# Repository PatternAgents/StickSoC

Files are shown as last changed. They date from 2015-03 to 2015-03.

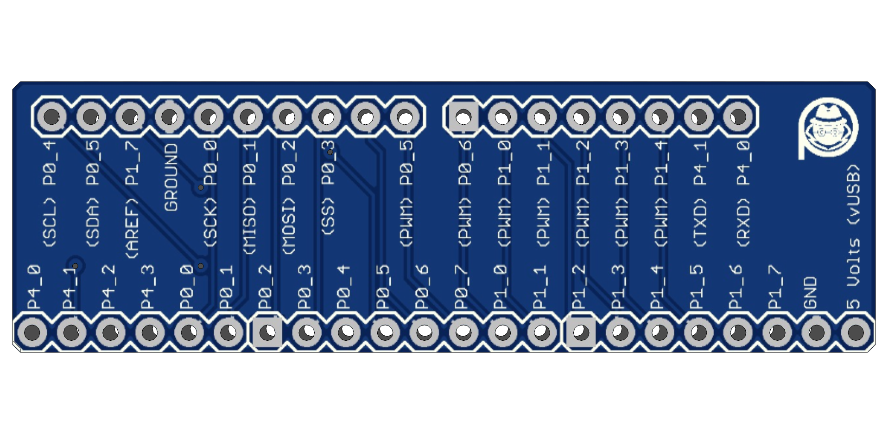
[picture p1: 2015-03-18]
StickSoc/StickSoc_Right/images/StickSoC_Right_top.png

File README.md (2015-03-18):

StickSoC
=============

PatternAgents StickSoC - add on boards for the Cypress CY8CKIT-049 (PSoC4)

[PatternAgents StickSoC  
*PatternAgents StickSoC*](http://www.patternagents.com/projects/StickSoC.html)

The PatternAgents StickSoC allows the Cypress CY8CKIT-049 board to accept Arduino type Shields.

Features:

        DC Barrel Jack for Providing VIN, 12Vdc-16Vdc to Shields that need it.

        PTC Resetable Fuse for VIN
	
        USB/5.0Vdc to 3.3Volt Voltage Regulator
	
	Arduino Uno/Leonardo Compatible Shield

You can read more about the PSoC4 Integrated Circuit used here : http://www.cypress.com/?mpn=CY8C4245AXI-483

[  
*Licensing CC BY-NC-SA 4.0*](http://creativecommons.org/licenses/by-nc-sa/4.0/)

PatternAgents uses the increasingly popular business model called "Dual Licensing" 
in which both the open source software distribution mechanism and traditional commercial software distribution models are combined.

Open Source Projects:        

If you are developing and distributing open source applications under the Creative Commons CC BY-NC-SA 4.0, 
as published by the Creative Commons Foundation, then you are free to use the PatternAgents hardware/software under the CC BY-NC-SA 4.0 license. 
Please note that CC BY-NC-SA 4.0 requires that all modifications to the original code as well as all Derivative Works 
must also be released under the terms of the CC BY-NC-SA 4.0 license.

Closed Source Projects:

If you are developing and distributing traditional closed source or commercial applications, 
you must purchase a PatternAgents commercial use license, 
which is specifically designed for users interested in retaining the proprietary status of their designs and code. 
All PatternAgents commercial licenses expressly supersede the CC BY-NC-SA 4.0 license. 
This means that when you license the PatternAgents software under a commercial license, 
you specifically do not use the software under the CC BY-NC-SA 4.0 license and therefore you are not subject to any of its terms.
        
If you would like to use our designs for your own personal or educational use, have at it! 

Our public design repository is available at <a href="https://github.com/patternagents">Github</a>.

If you would like to produce our designs for commercial use, or as products for sale, 
please contact us to arrange for a Commercial Use license. We have many other designs, 
as well as options and extras that are not released publicly. 
We will also customize designs, firmware, and software for a reasonable fee, just contact us to discuss your requirements.

THIS SOFTWARE IS PROVIDED BY THE CONTRIBUTORS "AS IS" AND WITHOUT ANY EXPRESS OR IMPLIED WARRANTIES, 
INCLUDING, BUT NOT LIMITED TO, THE IMPLIED WARRANTIES OF MERCHANTABILITY AND FITNESS FOR A PARTICULAR PURPOSE ARE DISCLAIMED. 
IN NO EVENT SHALL THE COPYRIGHT OWNER OR CONTRIBUTORS BE LIABLE FOR ANY DIRECT, INDIRECT, INCIDENTAL, SPECIAL, EXEMPLARY, 
OR CONSEQUENTIAL DAMAGES (INCLUDING, BUT NOT LIMITED TO, PROCUREMENT OF SUBSTITUTE GOODS OR SERVICES; LOSS OF USE, DATA, 
OR PROFITS; OR BUSINESS INTERRUPTION) HOWEVER CAUSED AND ON ANY THEORY OF LIABILITY, WHETHER IN CONTRACT, 
STRICT LIABILITY, OR TORT (INCLUDING NEGLIGENCE OR OTHERWISE) ARISING IN ANY WAY OUT OF THE USE OF THIS SOFTWARE, 
EVEN IF ADVISED OF THE POSSIBILITY OF SUCH DAMAGE. 

-------------------------------------------------------------------------------------------

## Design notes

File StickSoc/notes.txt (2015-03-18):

TODO: Next Revision
--------------------

1) Add Pullups to I2C lines.

2) Add Topside/Edge Switch & LEDs

3) Add NFET power sharing and 5V LDO

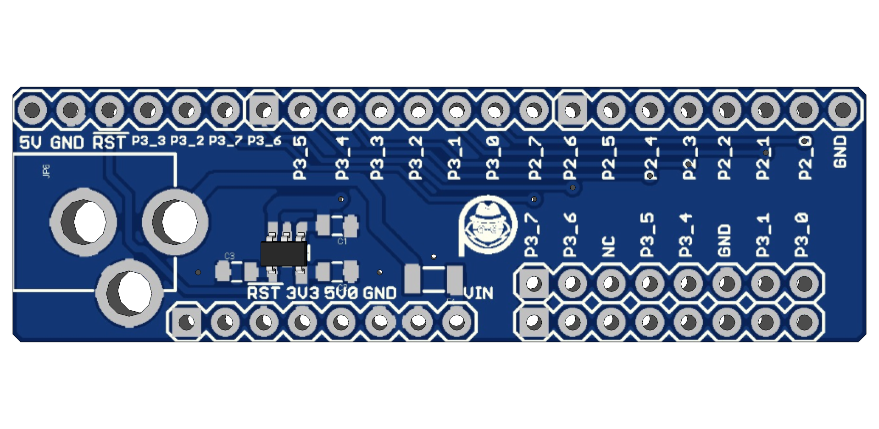
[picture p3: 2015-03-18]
StickSoc/StickSoC_Left/images/StickSoC_Left_top.png

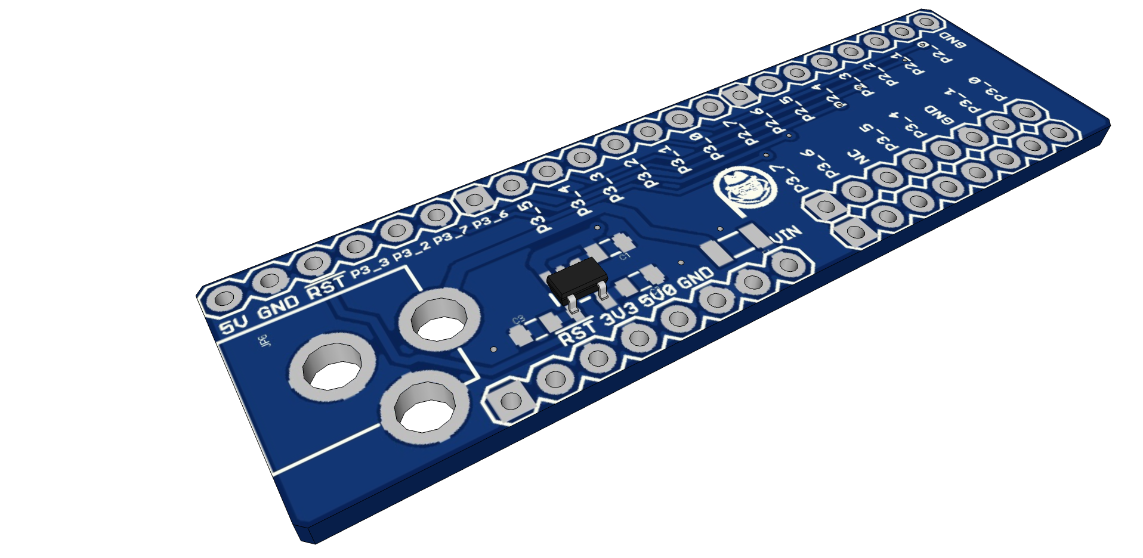
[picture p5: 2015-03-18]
StickSoc/StickSoC_Left/images/StickSoC_Left_iso.png

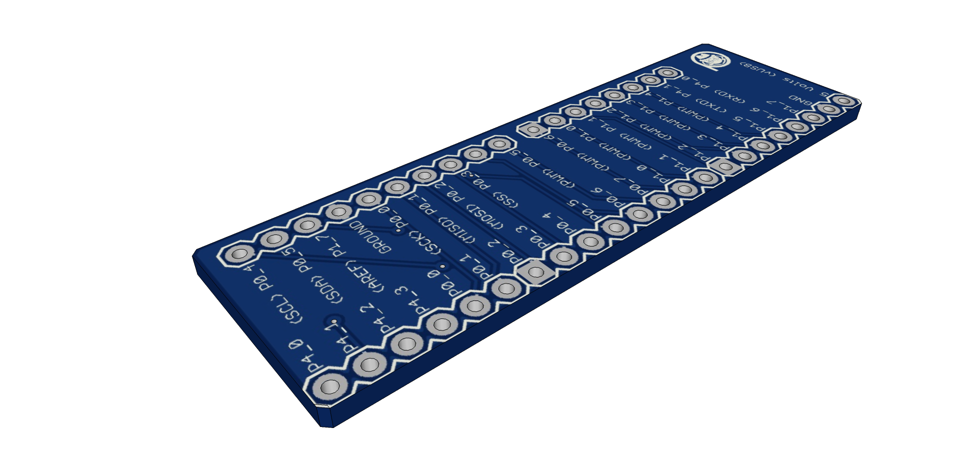
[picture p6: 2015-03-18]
StickSoc/StickSoc_Right/images/StickSoC_Right_iso.png

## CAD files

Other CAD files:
StickSoc/StickSoC_Left/eagleUp/StickSoC_Left.skp
StickSoc/StickSoc_Right/eagleUp/StickSoC_Right.skp

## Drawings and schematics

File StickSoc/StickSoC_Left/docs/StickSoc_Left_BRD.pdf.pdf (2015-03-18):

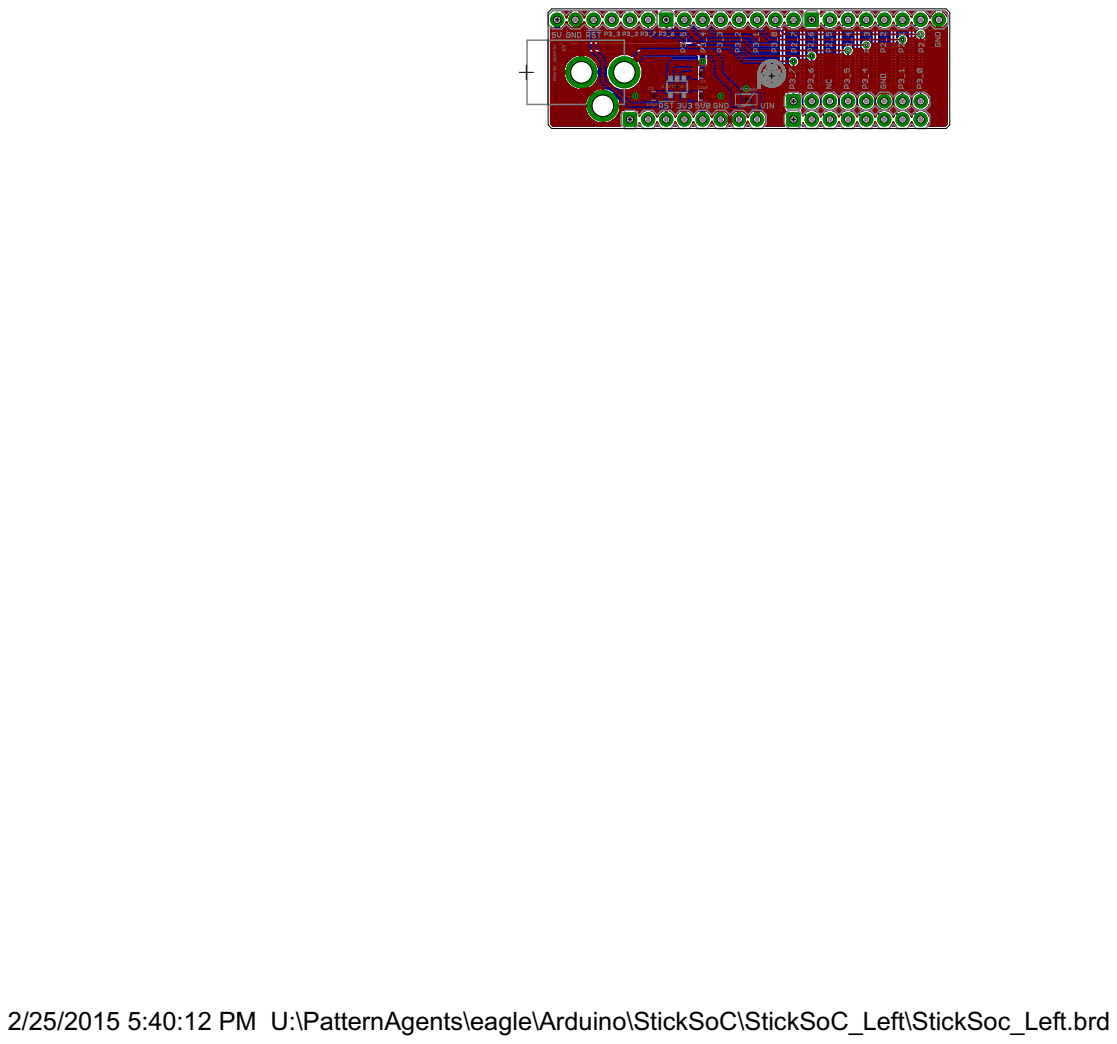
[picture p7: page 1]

2/25/2015 5:40:12 PM U:\PatternAgents\eagle\Arduino\StickSoC\StickSoC_Left\StickSoc_Left.brd

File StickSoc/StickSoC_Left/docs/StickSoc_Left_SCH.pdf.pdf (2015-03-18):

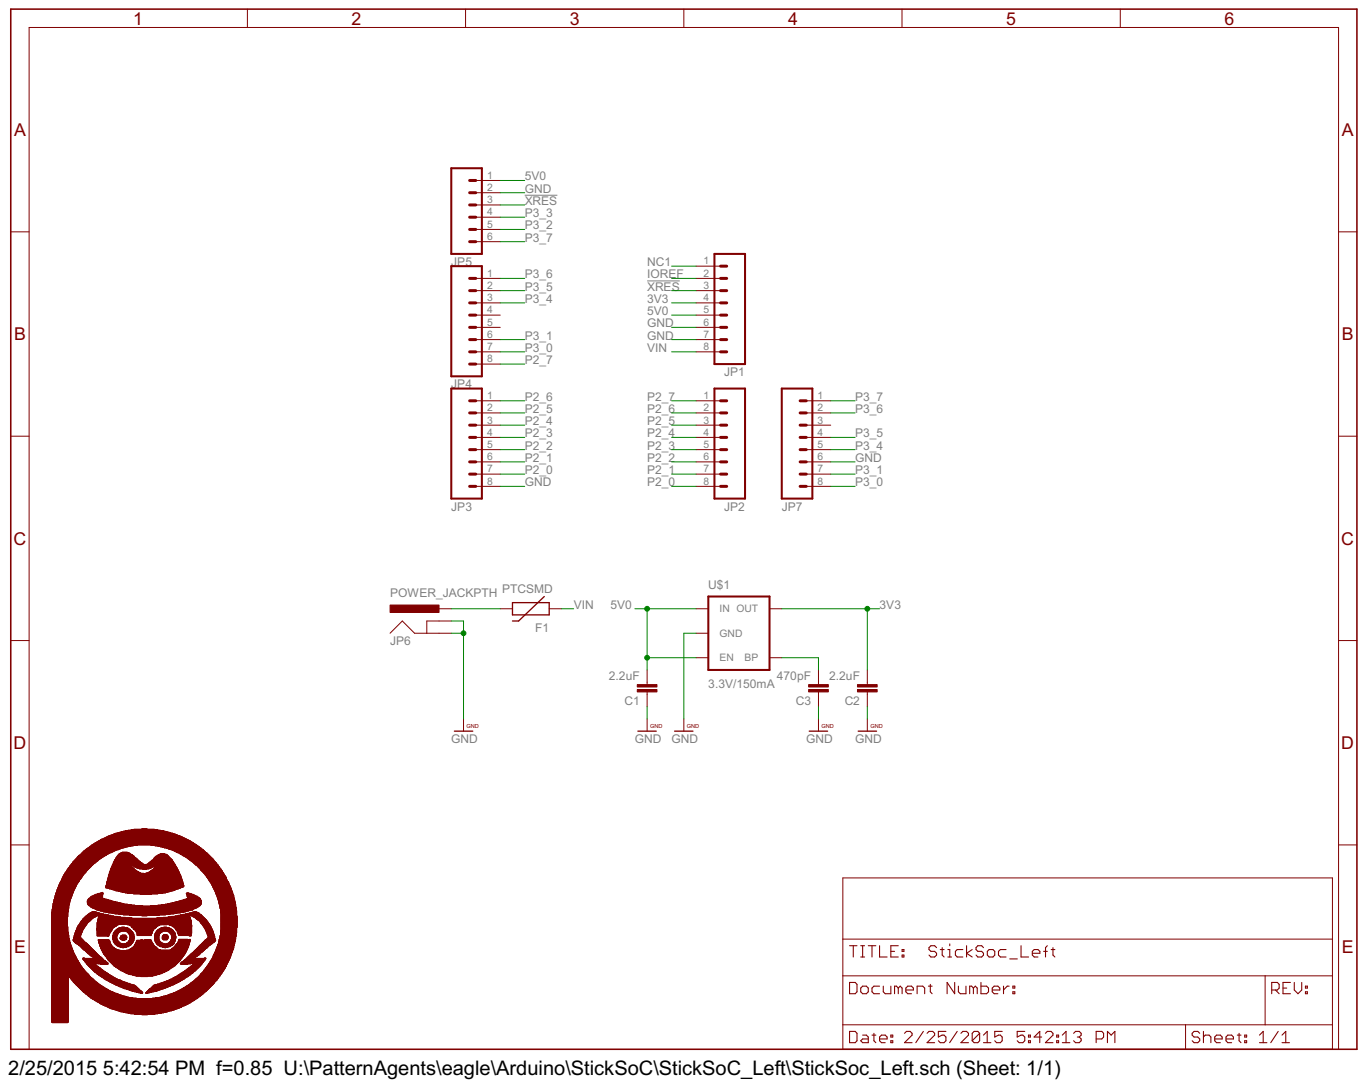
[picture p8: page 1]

2/25/2015 5:42:54 PM f=0.85 U:\PatternAgents\eagle\Arduino\StickSoC\StickSoC_Left\StickSoc_Left.sch (Sheet: 1/1)

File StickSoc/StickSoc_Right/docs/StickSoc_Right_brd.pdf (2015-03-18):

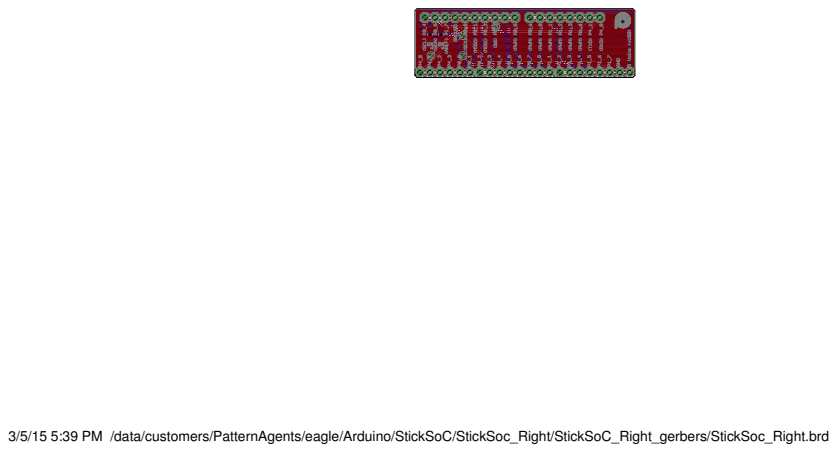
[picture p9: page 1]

3/5/15 5:39 PM /data/customers/PatternAgents/eagle/Arduino/StickSoC/StickSoc_Right/StickSoC_Right_gerbers/StickSoc_Right.brd

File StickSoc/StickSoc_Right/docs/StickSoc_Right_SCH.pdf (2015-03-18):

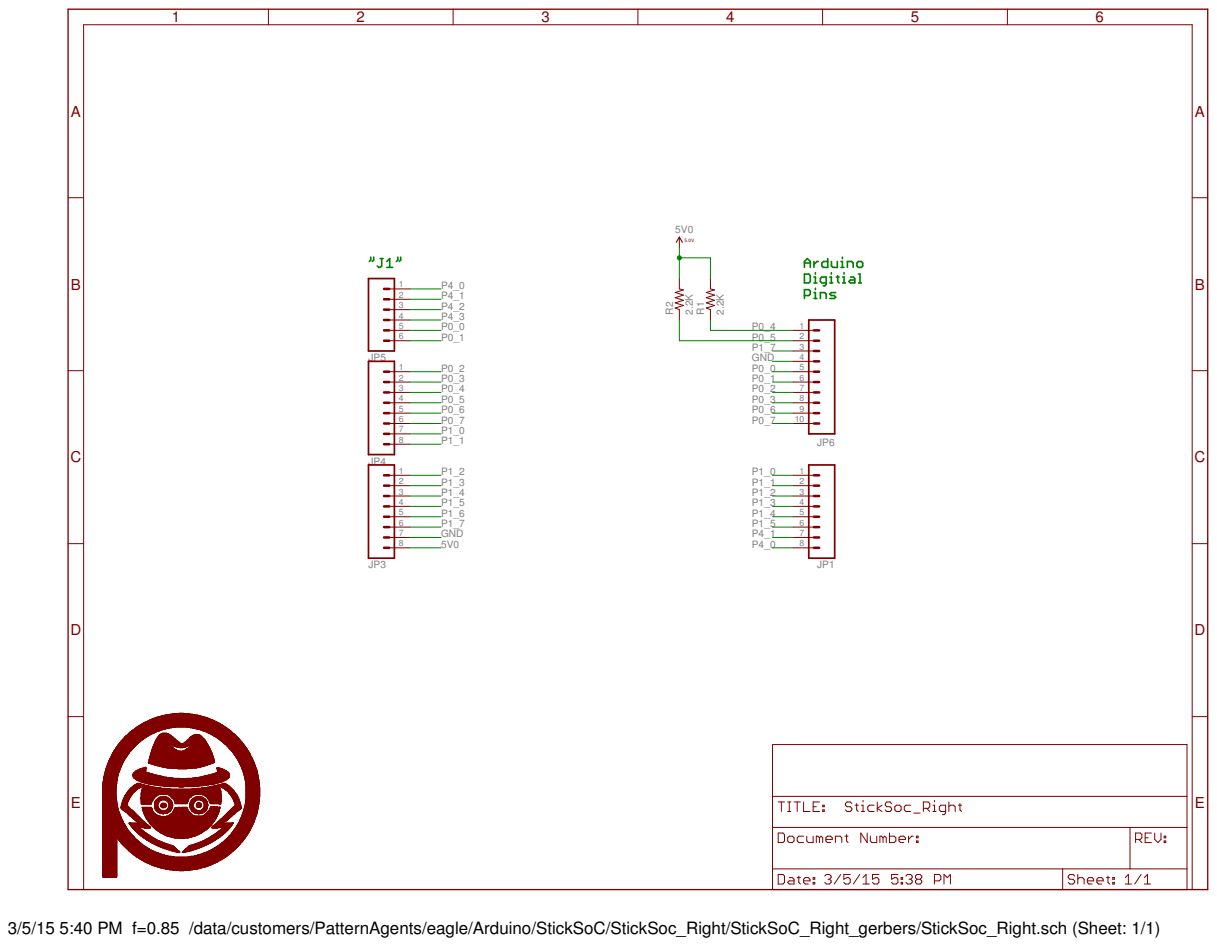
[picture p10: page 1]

3/5/15 5:40 PM f=0.85 /data/customers/PatternAgents/eagle/Arduino/StickSoC/StickSoc_Right/StickSoC_Right_gerbers/StickSoc_Right.sch (Sheet: 1/1)

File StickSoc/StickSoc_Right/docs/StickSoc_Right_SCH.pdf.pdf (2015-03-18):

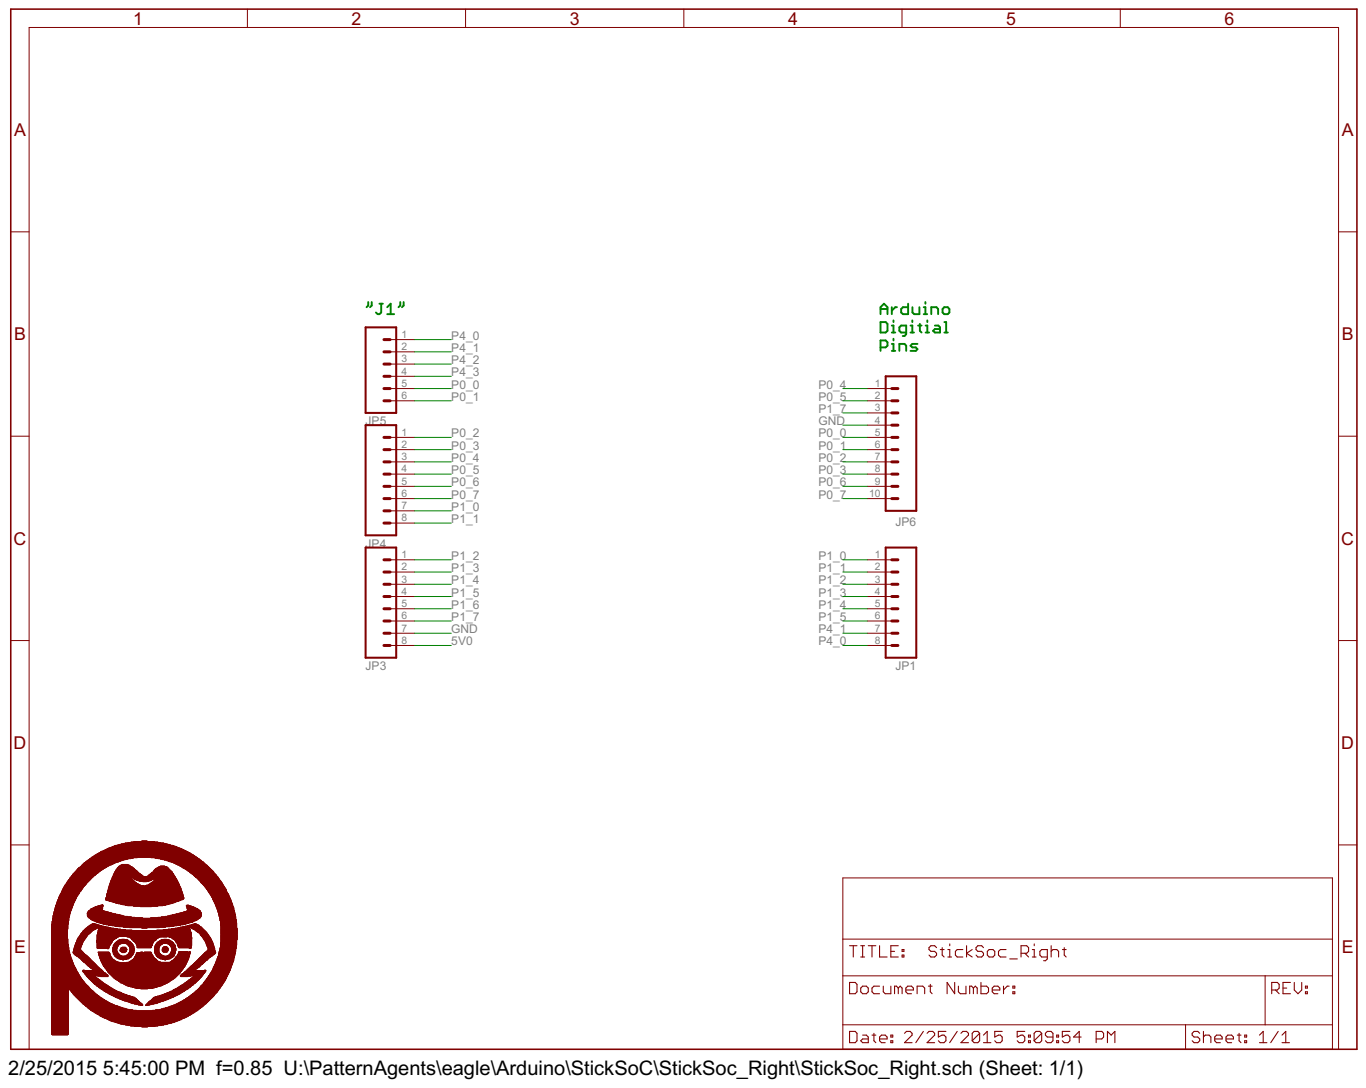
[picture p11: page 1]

2/25/2015 5:45:00 PM f=0.85 U:\PatternAgents\eagle\Arduino\StickSoC\StickSoc_Right\StickSoc_Right.sch (Sheet: 1/1)

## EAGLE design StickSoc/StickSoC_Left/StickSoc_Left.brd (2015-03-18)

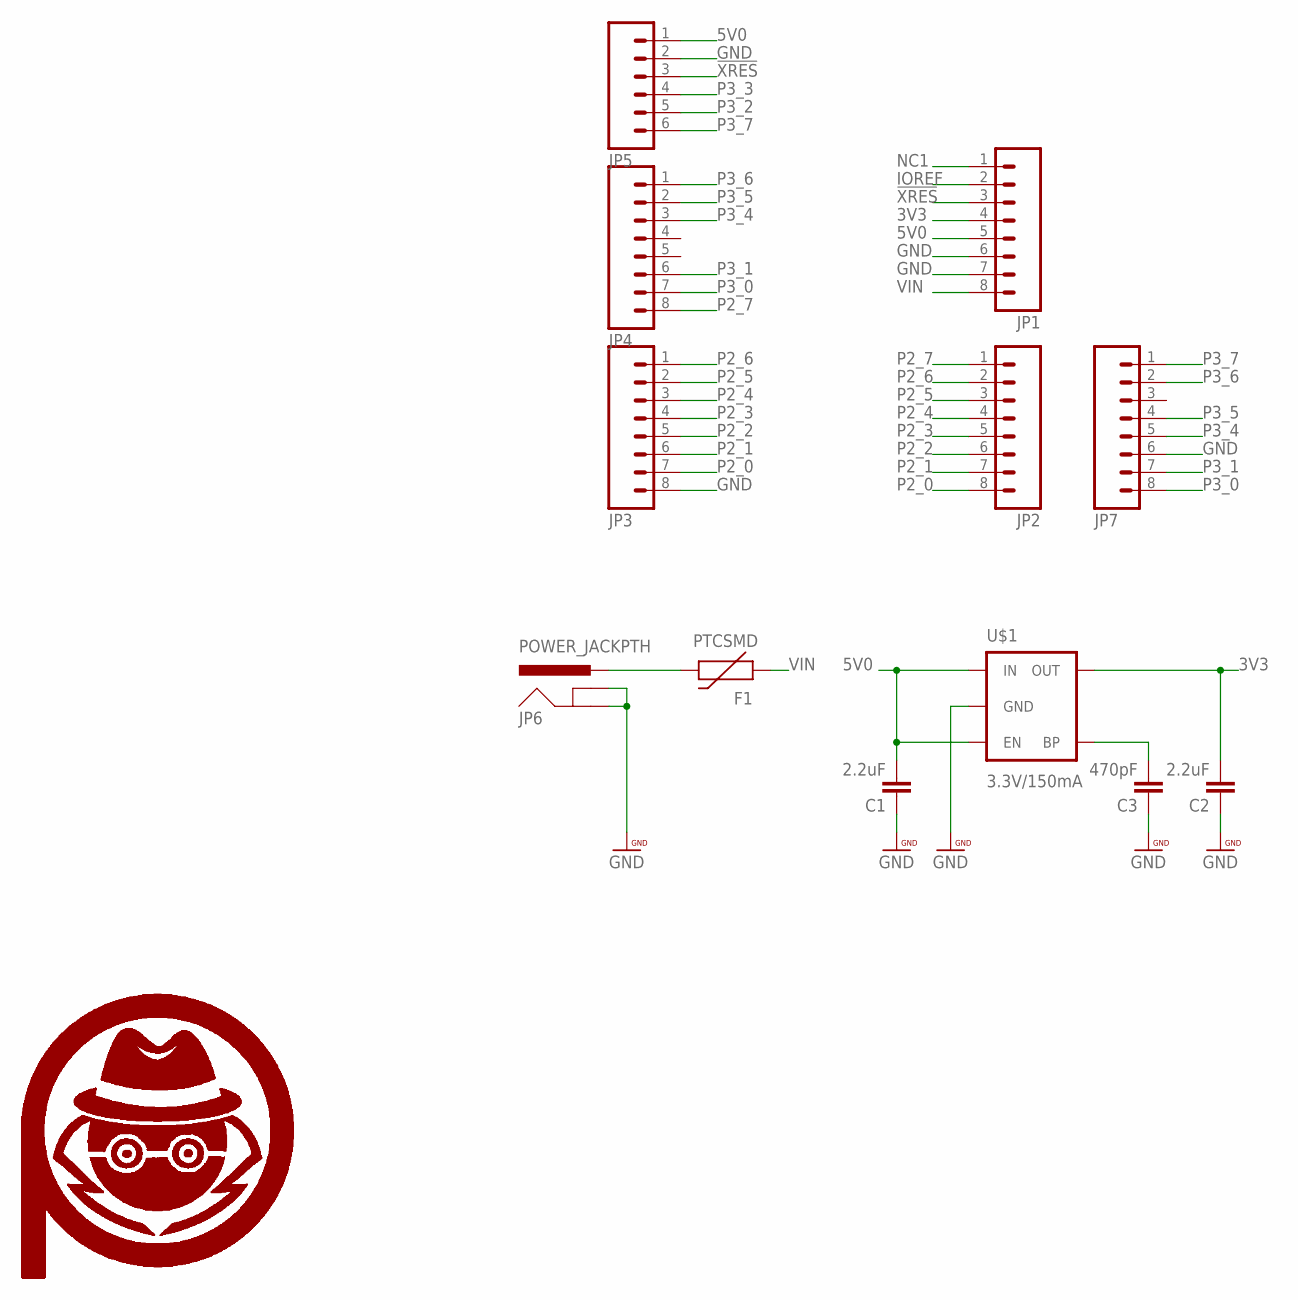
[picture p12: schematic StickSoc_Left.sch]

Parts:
C1, C2: 2.2uF; 0805
C3: 470pF; 0805
F1: PTCSMD; PTC-1206
JP1, JP2, JP3, JP4, JP7: M081X08; 1X08
JP5: M06SIP; 1X06
JP6: POWER_JACKPTH; POWER_JACK_PTH
U$1: 3.3V/150mA; SOT23-5
U$7, U$8: PA_LOGO_SYMSMALL; PA_LOGO_AGENT_SMALL_SYM

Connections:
3V3: C2.2, JP1.4, U$1.5 (OUT)
5V0: C1.2, JP1.5, JP5.1, U$1.1 (IN), U$1.3 (EN)
!XRES: JP1.3, JP5.3
GND: C1.1, C2.1, C3.1, JP1.6, JP1.7, JP3.8, JP5.2, JP6.GND, JP6.GNDBREAK, JP7.6, U$1.2 (GND)
IOREF: JP1.2
unnamed: F1.2, JP6.PWR
unnamed: C3.2, U$1.4 (BP)
NC1: JP1.1
P2_0: JP2.8, JP3.7
P2_1: JP2.7, JP3.6
P2_2: JP2.6, JP3.5
P2_3: JP2.5, JP3.4
P2_4: JP2.4, JP3.3
P2_5: JP2.3, JP3.2
P2_6: JP2.2, JP3.1
P2_7: JP2.1, JP4.8
P3_0: JP4.7, JP7.8
P3_1: JP4.6, JP7.7
P3_2: JP5.5
P3_3: JP5.4
P3_4: JP4.3, JP7.5
P3_5: JP4.2, JP7.4
P3_6: JP4.1, JP7.2
P3_7: JP5.6, JP7.1
VIN: F1.1, JP1.8

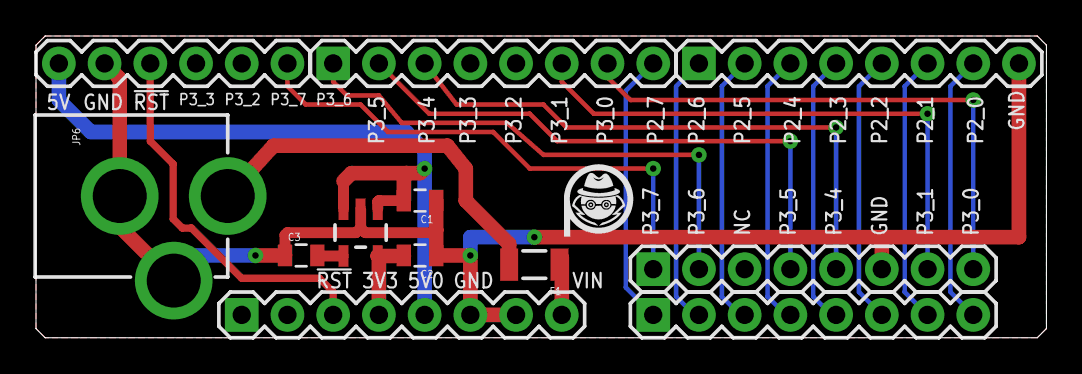
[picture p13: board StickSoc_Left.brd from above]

Board: 2 copper layers, 56.1 x 16.8 mm, 14 parts (1 on the bottom side), 21 nets.

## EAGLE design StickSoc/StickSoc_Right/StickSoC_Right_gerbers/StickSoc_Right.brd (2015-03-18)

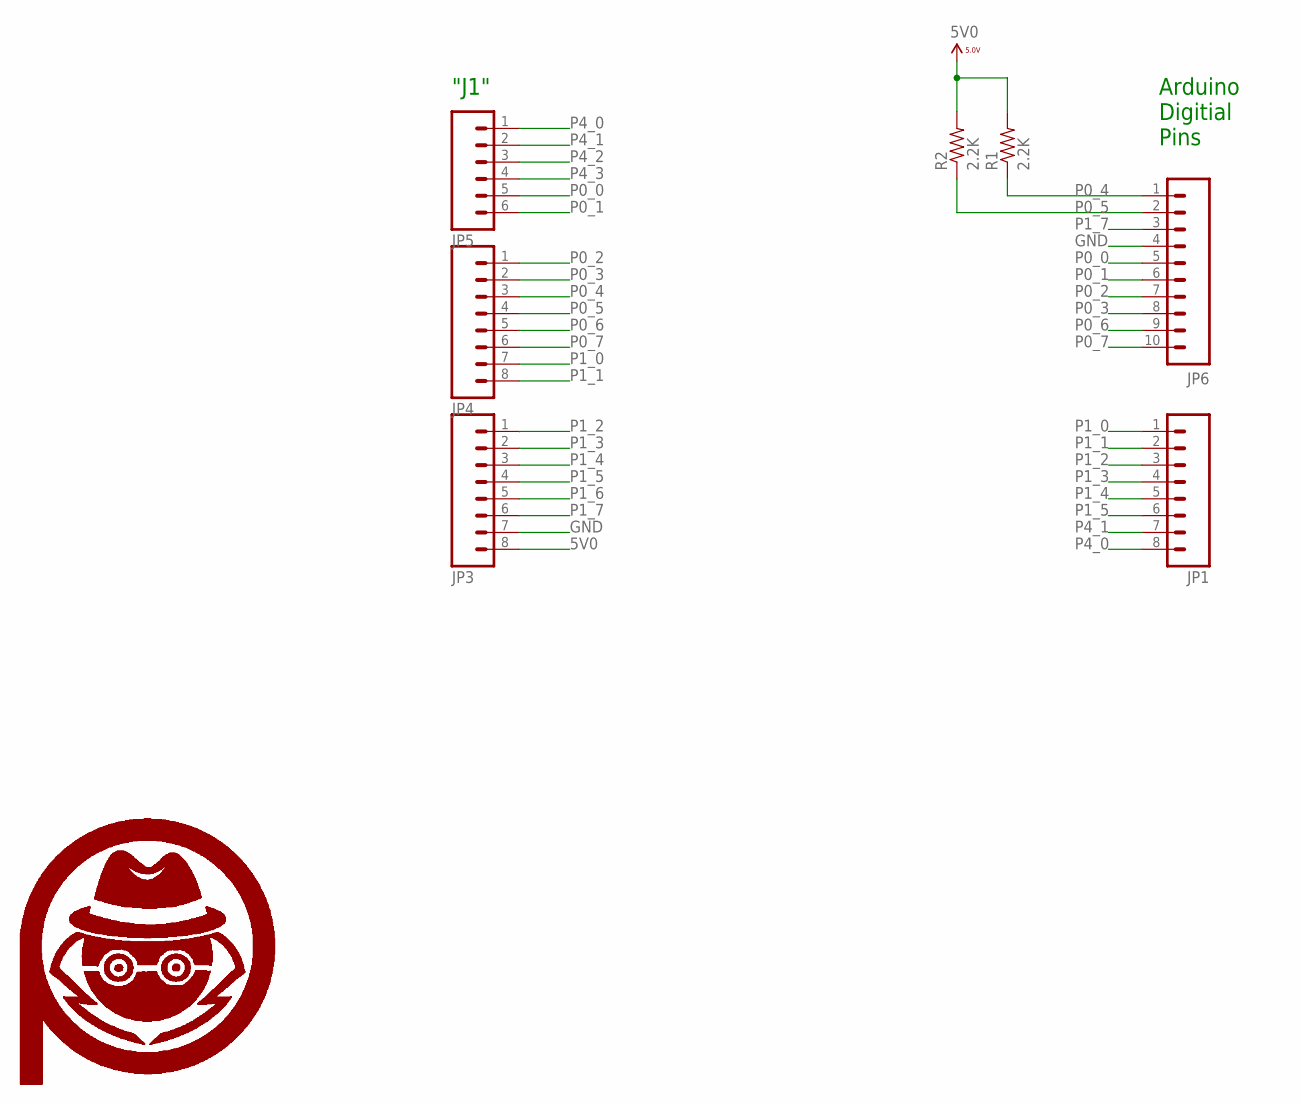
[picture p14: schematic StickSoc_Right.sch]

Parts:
JP1, JP3, JP4: M081X08; 1X08
JP5: M06SIP; 1X06
JP6: M10SILK_FEMALE_PTH; 1X10
R1, R2: 2.2K; 0805
U$1, U$2: PA_LOGO_SYMSMALL; PA_LOGO_AGENT_SMALL_SYM

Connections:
5V0: JP3.8, R1.2, R2.2
GND: JP3.7, JP6.4
P0_0: JP5.5, JP6.5
P0_1: JP5.6, JP6.6
P0_2: JP4.1, JP6.7
P0_3: JP4.2, JP6.8
P0_4: JP4.3, JP6.1, R1.1
P0_5: JP4.4, JP6.2, R2.1
P0_6: JP4.5, JP6.9
P0_7: JP4.6, JP6.10
P1_0: JP1.1, JP4.7
P1_1: JP1.2, JP4.8
P1_2: JP1.3, JP3.1
P1_3: JP1.4, JP3.2
P1_4: JP1.5, JP3.3
P1_5: JP1.6, JP3.4
P1_6: JP3.5
P1_7: JP3.6, JP6.3
P4_0: JP1.8, JP5.1
P4_1: JP1.7, JP5.2
P4_2: JP5.3
P4_3: JP5.4

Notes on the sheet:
"J1"
Arduino Digitial Pins

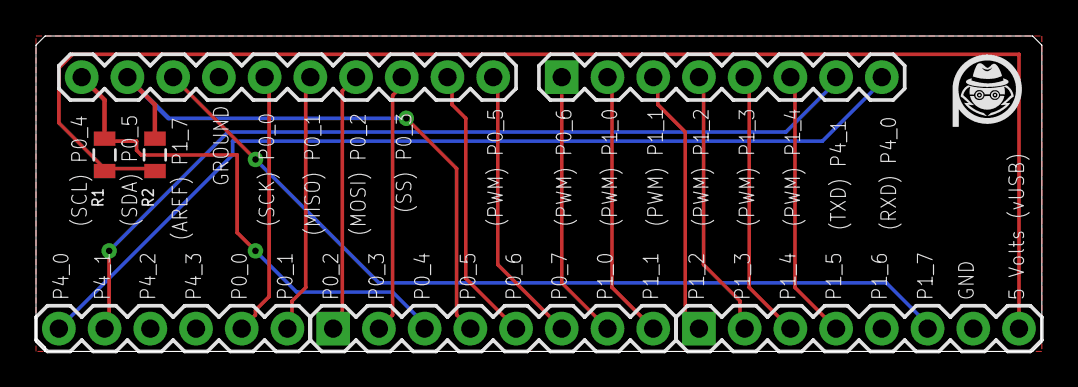
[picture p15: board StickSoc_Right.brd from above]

Board: 2 copper layers, 55.9 x 17.5 mm, 9 parts (1 on the bottom side), 19 nets.

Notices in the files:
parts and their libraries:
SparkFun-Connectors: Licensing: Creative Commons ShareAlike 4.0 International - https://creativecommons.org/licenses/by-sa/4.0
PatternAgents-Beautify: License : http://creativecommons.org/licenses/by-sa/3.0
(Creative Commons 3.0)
